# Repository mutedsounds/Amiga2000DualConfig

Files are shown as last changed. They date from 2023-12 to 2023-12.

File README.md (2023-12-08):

# Amiga2000DualConfig
Amiga 2000 Coprocessor Board to support 2 selectable CPUs, 2 selectable kickstart ROMs (+ 2x A/B configuration options) at boot or reset.

The **DualConfig** project was born out of an observation: some programs, games or demos don't work with all 680x0 processor models or all kickstart versions.

This project allows you to run the Amiga 2000 in legacy mode (68000 & Kickstart1.3) or with the legacy CPU and a more recent kickstart (68000 & Kickstart 3.x) or with a TerribleFire-type card (68030 & Kickstart3.x) for instance. It also provides two additional controls, one can be used to control a DF0 selector for instance. 

There is no need to power-off the Amiga to change the configuration. It can be changed anytime while the Amiga is powered-on. It will be taken in account on the next reset. Each of the 4 configuration parameters (CPU, Kickstart, param3, param4) can be selected using a latched SPST Off-On switch, with optional illumination.

The solution consists of two PCBs:

1. A "DualCpuAdapter" card that fits into the coprocessor slot. It is inspired by the [Open Amiga 2000 Copro Adapter](https://github.com/SukkoPera/OpenAmiga2000CoproAdapter) project. It allows:

   a) permanent installation of two CPUs in the Amiga with selection of one of the two installed CPUs via a SPST latched Off-On switch;

   b) selection of one of two Kickstarts via a SPST latch Off-On switch;

   c) optionally two other configuration parameters, each controlled via a latchsed SPST Off-On switch, one can be used to drive a ["DF0 Selector" board with a SPST control interface such as the one developped by Jussi Kilpelainen](https://jussikilpelainen.kapsi.fi/wordpress/?p=256)

   d) a led illumination driver for each parameter, enabling the use of illuminated switches 

2. A "DualKickAdapter" card that fits in the Kickstart DIP40 slot, allowing a permanent installation of two kickstart ROMs in the Amiga. Kickstart selection can be controlled either by the "DualCpuAdapter" card or by a DPDT On-On switch. 

The "DualKickAdapter" can be controlled by the "DualCpuAdapter" board by connecting 2 wires from the KICK1_CSn & KICK2_CSn header pins of the "DualCpuAdapter" board to the middle pins of the 2x3 header "SW DPDT", CSn_A & CSn_B.

The [CIT Relay GH Series](http://citrelay.com/view_switch.php?series=GH) are illuminated SPST latching off-on pushbutton switches with a small enough diameter of 10mm to be installed on the lower area of the bottom chassis of the Amiga 2000.

I made this project initially for personal use. It is operational and free of license. 

|:warning:**IMPORTANT: The KiCad files provided in the github repository have been translated from another commercial PCB design tool. The latest beta version (7.99) is required to open the files. I strongly advise to double check the KiCad PCB design files before sending to production. Please feel free to propose document updates.** |
|-----------------------------------------|

DualCpuAdapter, CPU1 side  | DualCpuAdapter, CPU2 side | DualKickAdapter
:-------------------------:|:-------------------------:|:-------------------------:
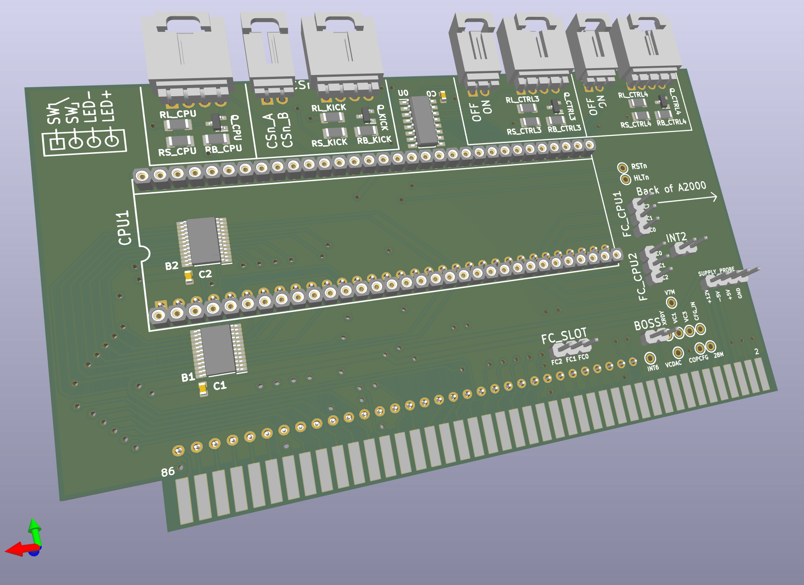
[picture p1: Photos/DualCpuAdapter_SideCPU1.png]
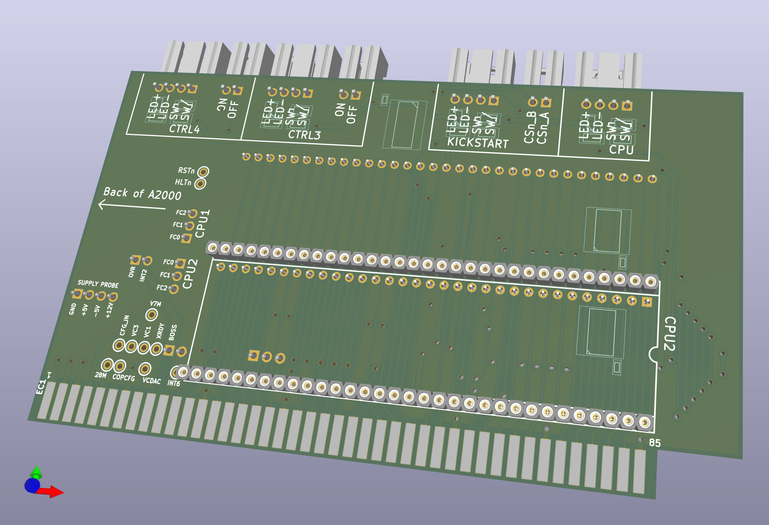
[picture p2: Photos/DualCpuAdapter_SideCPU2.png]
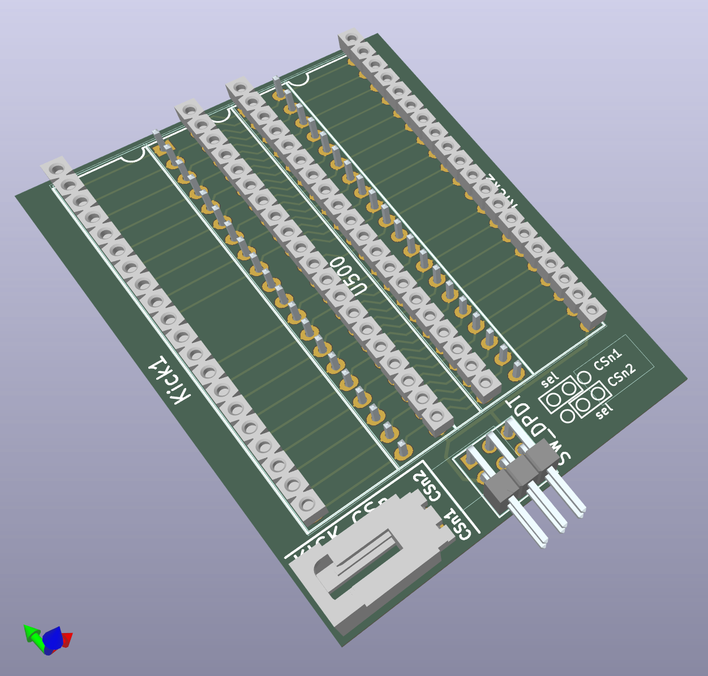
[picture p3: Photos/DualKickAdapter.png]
|  |  |  |

:camera:CIT Relay GH Series Pushbutton Switches to select CPU model (red on the left) and Kickstart version (green on the right)
|-----------------------------------------|

Legacy configuration 68000 (switch off) with Kickstart 1.3 (switch off) | Legacy CPU 68000 (switch off) with Kickstart 3.2.2 (switch on) | TF536 accelerator (switch on) with Kickstart 3.2.2 (switch on)
:-------------------------:|:-------------------------:|:-------------------------:
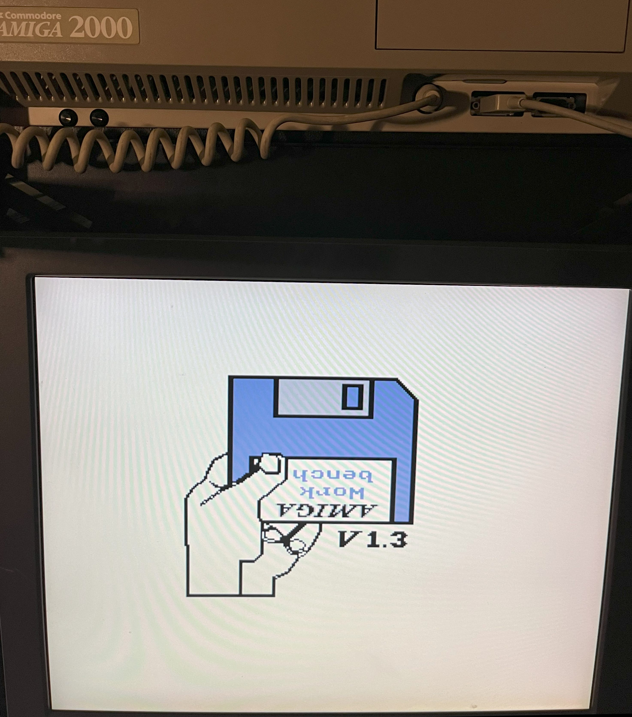
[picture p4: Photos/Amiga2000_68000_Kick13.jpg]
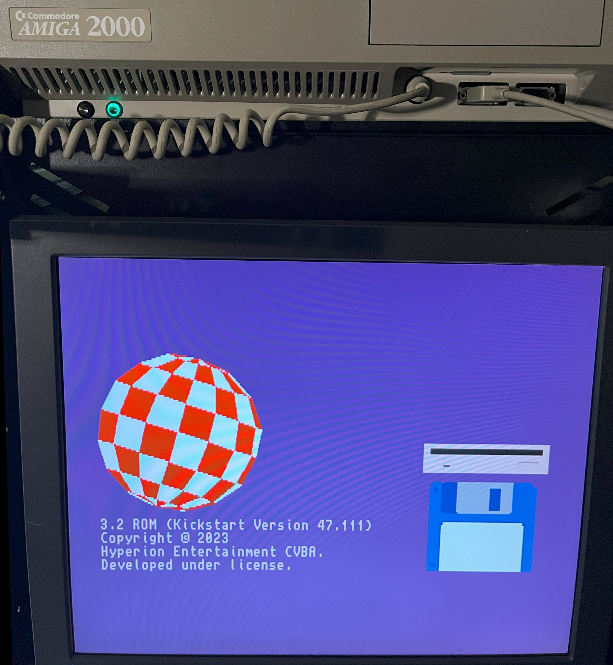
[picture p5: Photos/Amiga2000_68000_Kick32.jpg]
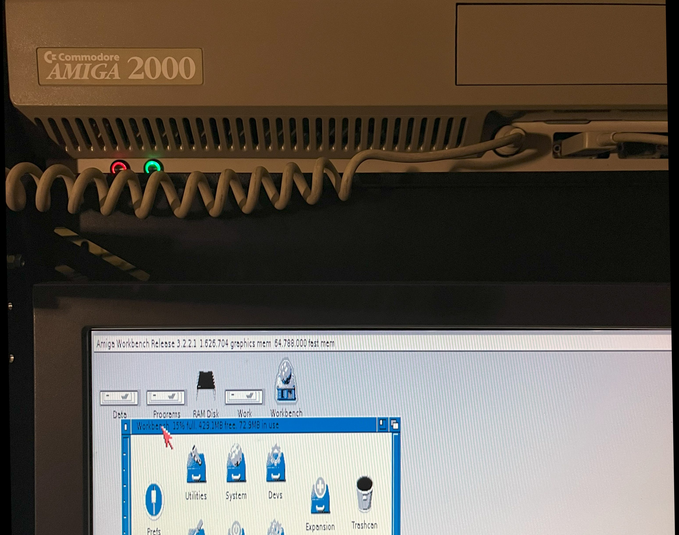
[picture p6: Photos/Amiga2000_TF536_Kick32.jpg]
|  |  |  |

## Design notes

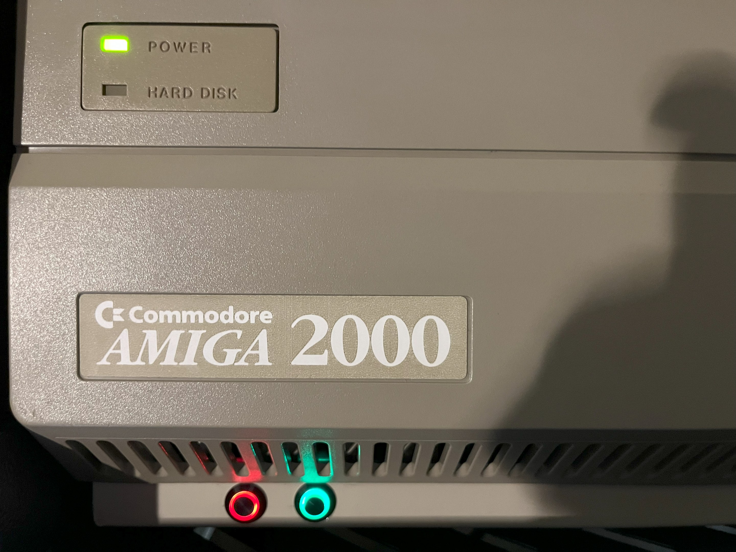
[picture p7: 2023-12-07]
Photos/Amiga2000_CPUred_KICKgreen_pushbuttons.jpg

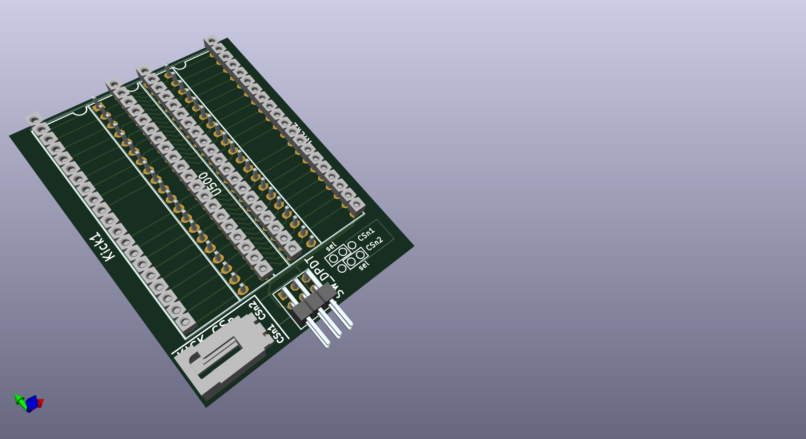
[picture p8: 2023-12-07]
DualKickAdapter/DualKickAdapter.png

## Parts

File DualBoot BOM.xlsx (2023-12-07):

Board | Designator | Digikey Part # | Manufacturer | Manufacturer Part | Description | Q. | Comments
Chassis | SW_CPU | 2449-GHLEBBRN-ND | CIT | GHLEBBRN | SPST Push-Button Off-On Latching D=10mm Illuminated Red | 1 | CPU selector, diameter small enough to be mounted on the front of the main chassis
DualCpu | SW_CPU | WM4902-ND | Molex | 705530003 | 2.54mm 1x4 pos, SL Header, Right Angle | 1 | Connect to CPU illuminated SPST switch (header must mate the cable receptacle)
DualCpu | SW_CPU | 900-2162711044-ND | Molex | 2162711044 | 2.54mm 1x4 pos, SL Female-to-Pigtail Off-the-Shelf (OTS) Cable Assembly, Length 600mm | 1 | Cable assembly to illuminated SPST switch (receptacle must mate the header)
Chassis | SW_KICK | 2449-GHLEBBGN-ND | CIT | GHLEBBGN | SPST Push-Button Off-On Latching D=10mm Illuminated Green | 1 | Kick selector, diameter small enough to be mounted on the front of the main chassis
DualCpu | SW_KICK | WM4902-ND | Molex | 705530003 | 2.54mm 1x4 pos, SL Header, Right Angle | 1 | Connect to KICK illuminated SPST switch (header must mate the cable receptacle)
DualCpu | SW_KICK | 900-2162711044-ND | Molex | 2162711044 | 2.54mm 1x4 pos, SL Female-to-Pigtail Off-the-Shelf (OTS) Cable Assembly, Length 600mm | 1 | Cable assembly to illuminated SPST switch (receptacle must mate the header)
DualCpu | KICK_CSn | WM4900-ND | Molex | 705530001 | 2.54mm 1x2 pos, SL Header, Right Angle | 1 | Connect to DualKick board
DualCpu | KICK_CSn | 900-2162701024-ND | Molex | 2162701024 | 2,54mm 1x2 pos, SL Male-to-SL Male Off-the-Shelf (OTS) Cable Assembly Length 600mm | 1 | Cable assembly to DualKick board
DualCpu | SW_CTRL3, SW_CTRL4 | WM4902-ND | Molex | 705530003 | 2.54mm 1x4 pos, SL Header, Right Angle | 0 | OPTIONAL, Connector to (illuminated) SPST switch
DualCpu | SW_CTRL3, SW_CTRL4 | 900-2162711044-ND | Molex | 2162711044 | 2.54mm 1x4 pos, SL Female-to-Pigtail Off-the-Shelf (OTS) Cable Assembly, Length 600mm | 0 | OPTIONAL, Cable assembly to (illuminated) SPST switch
DualCpu | CTRL3, CTRL4 | WM4900-ND | Molex | 705530001 | 2.54mm 1x2 pos, SL Header, Right Angle | 0 | OPTIONAL, Connector to control cable
DualCpu | SUPPLY | 952-3286-ND | Harwin | M20-9960445 | 2.54mm 1x4 pos, SL Header, Right Angle | 0 | OPTIONAL
DualCpu | BOSS, INT2 | M20-9770242-ND | Harwin | M20-9770242 | 2.54mm 1x2 pos Header, Straight | 0 | OPTIONAL
DualCpu | B1, B2 | 296-26449-5-ND | Texas Instruments | SN74CBTD3861PW | IC BUS SWITCH 10 X 1:1 24TSSOP | 2 | 10-bit FET bus to switch CPU outputs
DualCpu | C0, C1, C2 | 1276-1006-1-ND | Samsung E-M | CL10B104KA8NNNC | CAP CER 0.1UF 25V X7R 0603 | 3 | Decoupling caps
DualCpu | CPU1, CPU2 | 952-1938-ND | Harwin | D01-9973242 | CONN SOCKET SIP 32POS GOLD | 4 | 2x SIP 32-pin per CPU
DualCpu | Q_CPU, Q_CTRL3, Q_CTRL4, Q_KICK | 1727-1135-1-ND | Nexperia USA Inc. | PMBT2222A,235 | TRANS NPN 40V 0.6A TO236AB | 4 | LED driver for each control
DualCpu | RB_CPU, RB_CTRL3, RB_CTRL4, RB_KICK, RS_CPU, RS_CTRL3, RS_CTRL4, RS_KICK | 13-RC1206FR-134K7LCT-ND | YAGEO | RC1206FR-134K7L | RES 4.7K OHM 1% 1/4W 1206 | 8 | SW+LED driver for each control
DualCpu | RL_CPU, RL_CTRL3, RL_CTRL4, RL_KICK | 13-RC1206JR-13120RLCT-ND | YAGEO | RC1206JR-13120RL | RES 120 OHM 5% 1/4W 1206 | 4 | LED driver for each control
DualCpu | U0 | 296-31495-1-ND |  | CD4042BDR | IC QUAD CLOCKED D LATCH 16SOIC | 1 | Sample & Hold Switch Position on deassertion of reset
DualKick | SW_DPDT | WM4900-ND | Molex | 705530001 | 2.54mm 1x2 pos, SL Header, Right Angle | 1 | Connect to DualKick board, to be soldered in the mid 2 pins of the 2x3 footprint
DualKick | SW_DPDT | 10129382-906002BLF-ND | Amphenol | 10129382-906002BLF | CONN HEADER R/A 6POS 2.54MM | 0 | If direct connection to a DPDT switch, only the 2 middle pins are required to connect to the DualKick board
DualKick | U500 | ED7564-20-ND | Mill-Max Mfr Corp. | 800-10-020-10-002000 | CONN HEADER VERT 20POS 2.54MM | 2 | 2x SIP 20-pin male-male to plug the board in the U500 socket
DualKick | Kick1, Kick2 | Z12503-ND | Omron EMC | XR2C-2011-N | CONN SOCKET SIP 20POS GOLD | 4 | 2x SIP 20-pin socket per Kickstart

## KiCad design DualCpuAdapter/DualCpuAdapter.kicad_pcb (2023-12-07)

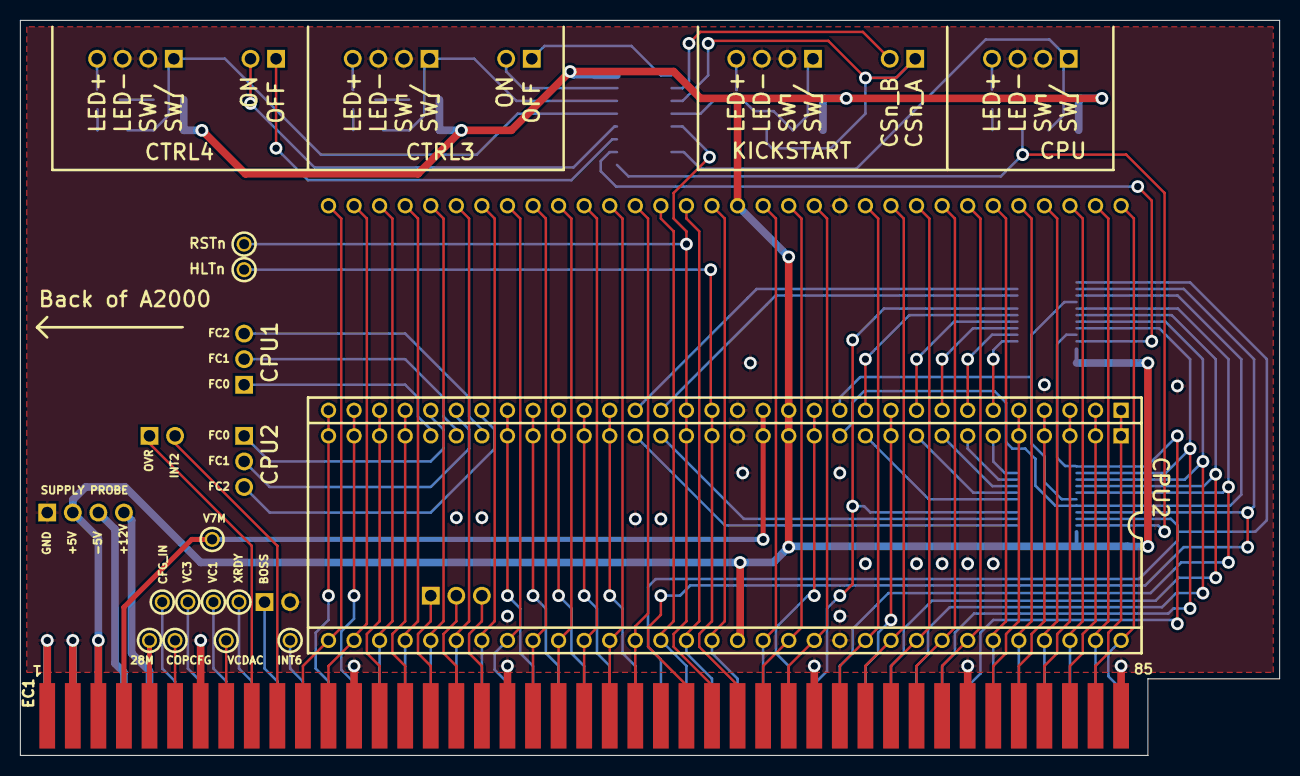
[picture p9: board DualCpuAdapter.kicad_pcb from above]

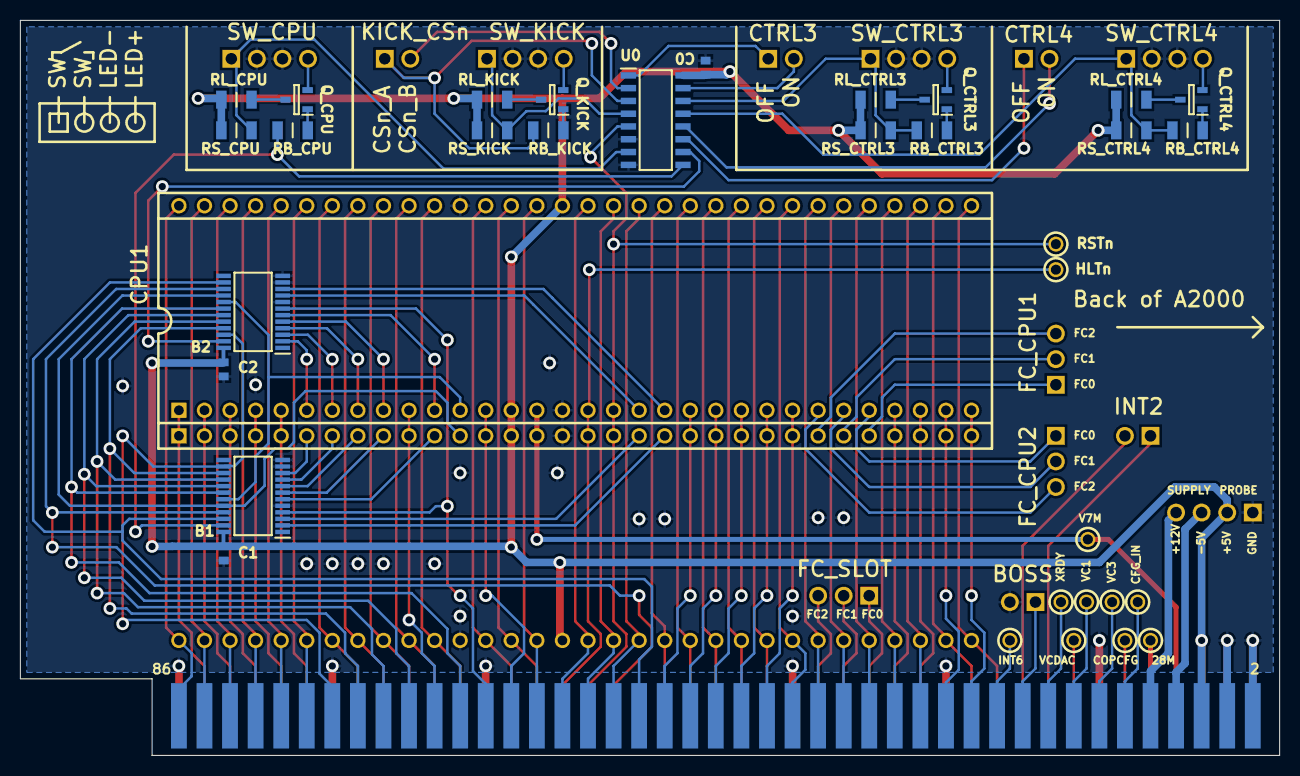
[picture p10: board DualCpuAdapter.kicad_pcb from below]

Board: 2 copper layers, 125.1 x 73.0 mm, 49 parts (47 on the bottom side), 111 nets.

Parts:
28M: Test Point; Test Point Throughhole 60mil
B1, B2: SN74CBTD3861PWR; SOP65P640X120-24N
BOSS: Header 1x2 SSS; Harwin M20-9770246
C0, C1, C2: X7R; SMD 1608 X95N
CFG_IN: Test Point; Test Point Throughhole 60mil
COPCFG: Test Point; Test Point Throughhole 60mil
CPU1, CPU2: MC68000P; DIP64 900mil 2xSIP32
CTRL3, CTRL4: Header 1x2 SSS; Molex 705530001
EC1: Card Edge 86pos; Card Edge 86DS 100mil
FC_CPU1, FC_CPU2: Header 1x3 SSS; Harwin M20-9770346
FC_SLOT: Header 1x3 SSS; Harwin M20-9770346
HLTn: Test Point; Test Point Throughhole 60mil
INT2: Header 1x2 SSS; Harwin M20-9770246
INT6: Test Point; Test Point Throughhole 60mil
KICK_CSn: Header 1x2 SSS; Molex 705530001
Q_CPU: PMBT2222A_235; SOT95P230X110-3N
Q_CTRL3, Q_CTRL4: PMBT2222A_235; SOT95P230X110-3N
Q_KICK: PMBT2222A_235; SOT95P230X110-3N
RB_CPU: %; SMD C3216 X 60N
RB_CTRL3, RB_CTRL4: %; SMD C3216 X 60N
RB_KICK: %; SMD C3216 X 60N
RL_CPU: %; SMD C3216 X 60N
RL_CTRL3, RL_CTRL4: %; SMD C3216 X 60N
RL_KICK: %; SMD C3216 X 60N
RSTn: Test Point; Test Point Throughhole 60mil
RS_CPU: %; SMD C3216 X 60N
RS_CTRL3, RS_CTRL4: %; SMD C3216 X 60N
RS_KICK: %; SMD C3216 X 60N
SUPPLY: Header 1x4 SSS; Harwin M20-9770446
SW_CPU: Header 1x4 SSS; Molex 705530003
SW_CTRL3, SW_CTRL4: Header 1x4 SSS; Molex 705530003
SW_KICK: Header 1x4 SSS; Molex 705530003
U0: CD4042BDR; SOIC127P600X175-16N
V7M: Test Point; Test Point Throughhole 60mil
VC1, VC3: Test Point; Test Point Throughhole 60mil
VCDAC: Test Point; Test Point Throughhole 60mil
XRDY: Test Point; Test Point Throughhole 60mil

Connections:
+5V: B1.24 (VCC), B2.24 (VCC), C0.1, C1.1, C2.1, CPU1.14 (VCC), CPU1.49 (VCC), CPU2.14 (VCC), CPU2.49 (VCC), EC1.5, EC1.6, RL_CPU.1, RL_CTRL3.1, RL_CTRL4.1, RL_KICK.1, RS_CPU.2, RS_CTRL3.2, RS_CTRL4.2, RS_KICK.2, SUPPLY.2, U0.16 (VDD)
+12V: EC1.10, SUPPLY.4
-5V: EC1.8, SUPPLY.3
/A1: CPU1.29 (A1), CPU2.29 (A1), EC1.29
/A2: CPU1.30 (A2), CPU2.30 (A2), EC1.27
/A3: CPU1.31 (A3), CPU2.31 (A3), EC1.26
/A4: CPU1.32 (A4), CPU2.32 (A4), EC1.24
/A5: CPU1.33 (A5), CPU2.33 (A5), EC1.21
/A6: CPU1.34 (A6), CPU2.34 (A6), EC1.23
/A7: CPU1.35 (A7), CPU2.35 (A7), EC1.28
/A8: CPU1.36 (A8), CPU2.36 (A8), EC1.30
/A9: CPU1.37 (A9), CPU2.37 (A9), EC1.32
/A10: CPU1.38 (A10), CPU2.38 (A10), EC1.34
/A11: CPU1.39 (A11), CPU2.39 (A11), EC1.36
/A12: CPU1.40 (A12), CPU2.40 (A12), EC1.38
/A13: CPU1.41 (A13), CPU2.41 (A13), EC1.39
/A14: CPU1.42 (A14), CPU2.42 (A14), EC1.41
/A15: CPU1.43 (A15), CPU2.43 (A15), EC1.43
/A16: CPU1.44 (A16), CPU2.44 (A16), EC1.45
/A17: CPU1.45 (A17), CPU2.45 (A17), EC1.47
/A18: CPU1.46 (A18), CPU2.46 (A18), EC1.52
/A19: CPU1.47 (A19), CPU2.47 (A19), EC1.54
/A20: CPU1.48 (A20), CPU2.48 (A20), EC1.56
/A21: CPU1.50 (A21), CPU2.50 (A21), EC1.58
/A22: CPU1.51 (A22), CPU2.51 (A22), EC1.57
/A23: CPU1.52 (A23), CPU2.52 (A23), EC1.59
/ASn_CPU1: B1.10 (A9), CPU1.6 (~AS)
/ASn_CPU2: B2.2 (A1), CPU2.6 (~AS)
/ASn_SLOT: B1.14 (B9), B2.22 (B1), EC1.74
/BERRn: CPU1.22 (~BERR), CPU2.22 (~BERR), EC1.46
/BGACKn_CPU1: B1.20 (B3), B2.16 (B7), CPU1.12 (~BGACK)
/BGACKn_CPU2: B1.19 (B4), B2.17 (B6), CPU2.12 (~BGACK)
/BGACKn_SLOT: B1.4 (A3), B2.7 (A6), EC1.62
/BGn_CPU1: B1.6 (A5), CPU1.11 (~BG)
/BGn_CPU2: B2.6 (A5), CPU2.11 (~BG)
/BGn_SLOT: B1.18 (B5), B2.18 (B5), EC1.64
/BRn: CPU1.13 (~BR), CPU2.13 (~BR), EC1.60
/CPU1_SELn: B1.23 (~OE), U0.9 (~Q2)
/CPU2_SELn: B2.23 (~OE), U0.10 (Q2)
/CTRL3_OFF: CTRL3.1, U0.1 (Q4)
/CTRL3_ON: CTRL3.2, U0.15 (~Q4)
/CTRL3_SW: RB_CTRL3.1, RS_CTRL3.1, SW_CTRL3.1, U0.14 (D4)
/CTRL4_OFF: CTRL4.1, U0.11 (Q3)
/CTRL4_ON: CTRL4.2, U0.12 (~Q3)
/CTRL4_SW: RB_CTRL4.1, RS_CTRL4.1, SW_CTRL4.1, U0.13 (D3)
/D0: CPU1.5 (D0), CPU2.5 (D0), EC1.75
/D1: CPU1.4 (D1), CPU2.4 (D1), EC1.77
/D2: CPU1.3 (D2), CPU2.3 (D2), EC1.79
/D3: CPU1.2 (D3), CPU2.2 (D3), EC1.81
/D4: CPU1.1 (D4), CPU2.1 (D4), EC1.83
/D5: CPU1.64 (D5), CPU2.64 (D5), EC1.86
/D6: CPU1.63 (D6), CPU2.63 (D6), EC1.84
/D7: CPU1.62 (D7), CPU2.62 (D7), EC1.82
/D8: CPU1.61 (D8), CPU2.61 (D8), EC1.80
/D9: CPU1.60 (D9), CPU2.60 (D9), EC1.78
/D10: CPU1.59 (D10), CPU2.59 (D10), EC1.76
/D11: CPU1.58 (D11), CPU2.58 (D11), EC1.71
/D12: CPU1.57 (D12), CPU2.57 (D12), EC1.69
/D13: CPU1.56 (D13), CPU2.56 (D13), EC1.67
/D14: CPU1.55 (D14), CPU2.55 (D14), EC1.65
/D15: CPU1.54 (D15), CPU2.54 (D15), EC1.63
/DTACKn: CPU1.10 (~DTACK), CPU2.10 (~DTACK), EC1.66
/E_CPU1: B1.2 (A1), CPU1.20 (E)
/E_CPU2: B2.10 (A9), CPU2.20 (E)
/E_SLOT: B1.22 (B1), B2.14 (B9), EC1.50
/FC0_CPU1: CPU1.28 (FC0), FC_CPU1.1
/FC0_CPU2: CPU2.28 (FC0), FC_CPU2.1
/FC1_CPU1: CPU1.27 (FC1), FC_CPU1.2
/FC1_CPU2: CPU2.27 (FC1), FC_CPU2.2
/FC2_CPU1: CPU1.26 (FC2), FC_CPU1.3
/FC2_CPU2: CPU2.26 (FC2), FC_CPU2.3
/HLTn: CPU1.17 (~HALT), CPU2.17 (~HALT), EC1.55
/INT2: EC1.19, INT2.2
/INT6: EC1.22, INT6.1
/IPL0n: CPU1.25 (~IPL0), CPU2.25 (~IPL0), EC1.40
/IPL1n: CPU1.24 (~IPL1), CPU2.24 (~IPL1), EC1.42
/IPL2n: CPU1.23 (~IPL2), CPU2.23 (~IPL2), EC1.44
/LDSn_CPU1: B1.8 (A7), CPU1.8 (~LDS)
/LDSn_CPU2: B2.4 (A3), CPU2.8 (~LDS)
/LDSn_SLOT: B1.16 (B7), B2.20 (B3), EC1.70
/OVR: EC1.17, INT2.1
/RSTn: CPU1.18 (~RST), CPU2.18 (~RST), EC1.53, U0.5 (CLOCK)
/RWn_CPU1: B1.7 (A6), CPU1.9 (R/~W)
/RWn_CPU2: B2.5 (A4), CPU2.9 (R/~W)
/RWn_SLOT: B1.17 (B6), B2.19 (B4), EC1.68
/UDSn_CPU1: B1.9 (A8), CPU1.7 (~UDS)
/UDSn_CPU2: B2.3 (A2), CPU2.7 (~UDS)
/UDSn_SLOT: B1.15 (B8), B2.21 (B2), EC1.72
/V7M: CPU1.15 (CLK), CPU2.15 (CLK), EC1.7
/VC1: EC1.16, VC1.1
/VC3: EC1.14, VC3.1
/VMAn_CPU1: B1.3 (A2), CPU1.19 (~VMA)
/VMAn_CPU2: B2.9 (A8), CPU2.19 (~VMA)
/VMAn_SLOT: B1.21 (B2), B2.15 (B8), EC1.51
/VPAn: CPU1.21 (~VPA), CPU2.21 (~VPA), EC1.48
CPU_LED: Q_CPU.2, SW_CPU.4
CPU_SW: RS_CPU.1, SW_CPU.1
GND: B1.5 (A4), B1.11 (A10), B1.12 (GND), B2.8 (A7), B2.11 (A10), B2.12 (GND), BOSS.2, C0.2, C1.2, C2.2, CPU1.16 (GND), CPU1.53 (GND), CPU2.16 (GND), CPU2.53 (GND), EC1.1, EC1.2, EC1.3, EC1.4, EC1.13, EC1.25, EC1.37, EC1.49, EC1.61, EC1.73, EC1.85, SUPPLY.1, SW_CPU.2, SW_CPU.3, SW_CTRL3.2, SW_CTRL3.3, SW_CTRL4.2, SW_CTRL4.3, SW_KICK.2, SW_KICK.3, U0.6 (POLARITY), U0.8 (VSS)
KICK1_CSN: KICK_CSn.1, RB_KICK.1
KICK_SW: RS_KICK.1, SW_KICK.1
unnamed: Q_CTRL3.1 (B), RB_CTRL3.2
unnamed: Q_CTRL3.3 (C), RL_CTRL3.2
unnamed: Q_CTRL3.2 (E), SW_CTRL3.4
unnamed: Q_CTRL4.1 (B), RB_CTRL4.2
unnamed: Q_CTRL4.3 (C), RL_CTRL4.2
unnamed: Q_CTRL4.2 (E), SW_CTRL4.4
NetQ_CPU_1: Q_CPU.1, RB_CPU.2
NetQ_CPU_3: Q_CPU.3, RL_CPU.2
NetQ_KICK_1: Q_KICK.1, RB_KICK.2
NetQ_KICK_2: Q_KICK.2, SW_KICK.4
NetQ_KICK_3: Q_KICK.3, RL_KICK.2

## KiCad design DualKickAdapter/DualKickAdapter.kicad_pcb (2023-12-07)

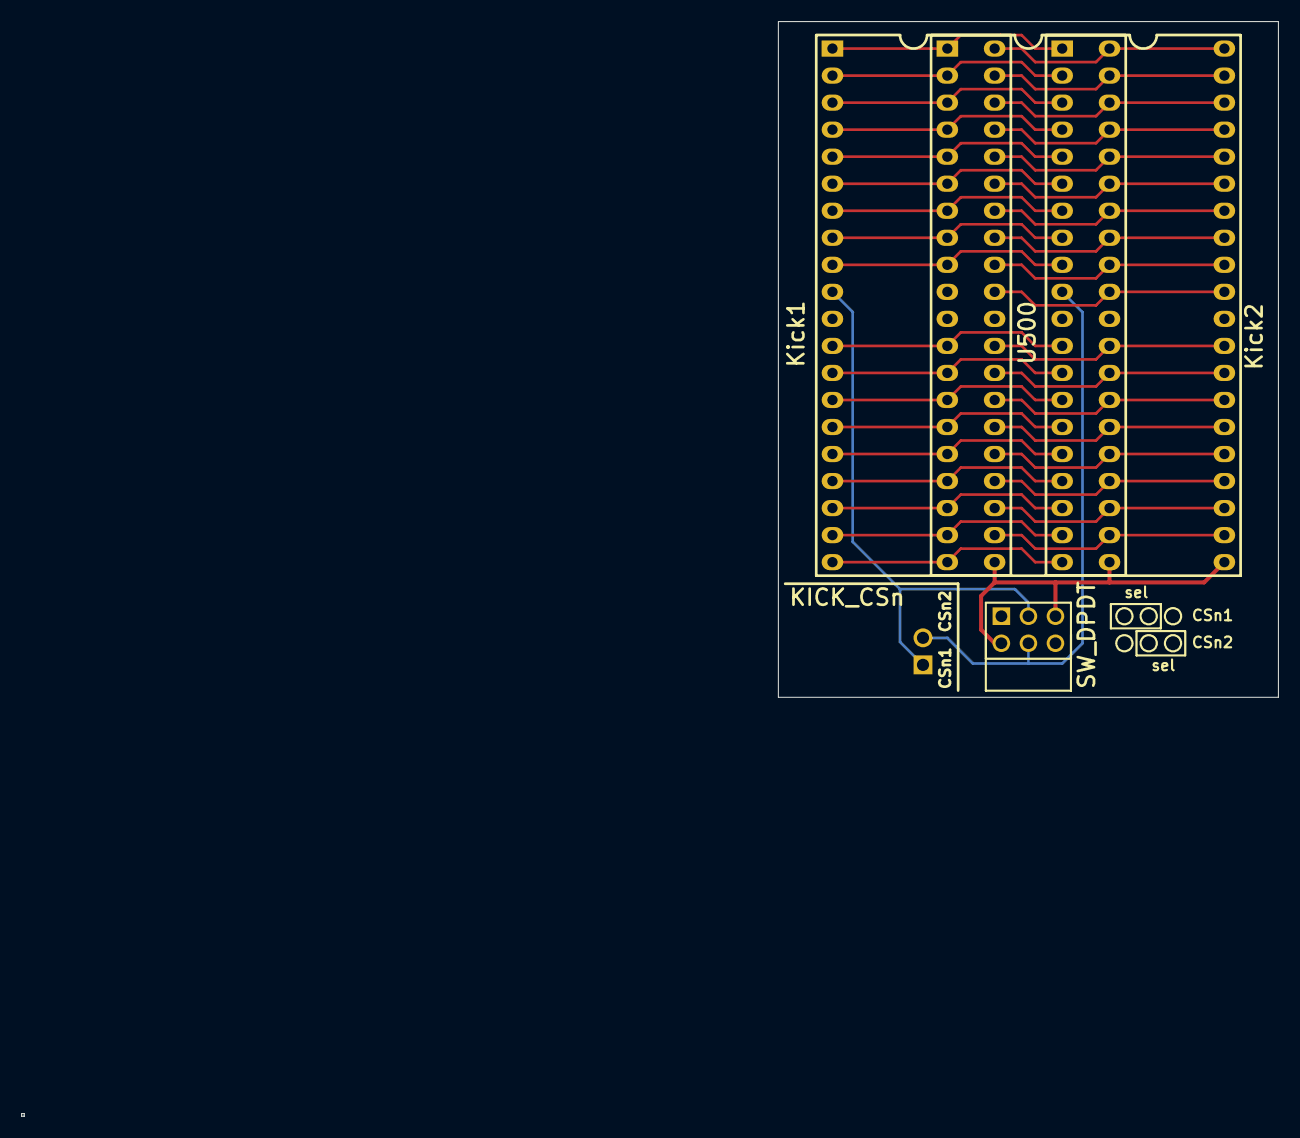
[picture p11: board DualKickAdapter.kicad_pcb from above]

Board: 2 copper layers, 47.0 x 63.5 mm, 5 parts (0 on the bottom side), 40 nets.

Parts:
KICK_CSn: Header 1x2 DSS; Molex 705530001
Kick1, Kick2: DIP40 2x20 600mil; DIP40 600mil 2xSIP20 oval
SW_DPDT: Header 2x3 DSS; Amphenol 10129382-906002BLF alt
U500: DIP40 2x20 600mil; DIP40 600mil 2xSIP20 spacer oval

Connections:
A0: Kick1.9, Kick2.9, U500.9
A1: Kick1.8, Kick2.8, U500.8
A2: Kick1.7, Kick2.7, U500.7
A3: Kick1.6, Kick2.6, U500.6
A4: Kick1.5, Kick2.5, U500.5
A5: Kick1.4, Kick2.4, U500.4
A6: Kick1.3, Kick2.3, U500.3
A7: Kick1.2, Kick2.2, U500.2
A8: Kick1.40, Kick2.40, U500.40
A9: Kick1.39, Kick2.39, U500.39
A10: Kick1.38, Kick2.38, U500.38
A11: Kick1.37, Kick2.37, U500.37
A12: Kick1.36, Kick2.36, U500.36
A13: Kick1.35, Kick2.35, U500.35
A14: Kick1.34, Kick2.34, U500.34
A15: Kick1.33, Kick2.33, U500.33
A16: Kick1.32, Kick2.32, U500.32
A17: Kick1.31, Kick2.31, U500.31
CSN_A: KICK_CSn.1, SW_DPDT.3
CSN_B: KICK_CSn.2, SW_DPDT.4
D0: Kick1.13, Kick2.13, U500.13
D1: Kick1.15, Kick2.15, U500.15
D2: Kick1.17, Kick2.17, U500.17
D3: Kick1.19, Kick2.19, U500.19
D4: Kick1.22, Kick2.22, U500.22
D5: Kick1.24, Kick2.24, U500.24
D6: Kick1.26, Kick2.26, U500.26
D7: Kick1.28, Kick2.28, U500.28
D8: Kick1.14, Kick2.14, U500.14
D9: Kick1.16, Kick2.16, U500.16
D10: Kick1.18, Kick2.18, U500.18
D11: Kick1.20, Kick2.20, U500.20
D12: Kick1.23, Kick2.23, U500.23
D13: Kick1.25, Kick2.25, U500.25
D14: Kick1.27, Kick2.27, U500.27
D15: Kick1.29, Kick2.29, U500.29
GND: Kick1.11, Kick1.30, Kick2.11, Kick2.30, SW_DPDT.1, SW_DPDT.6, U500.11, U500.30
NC: Kick1.1, Kick2.1, U500.1
OEn: Kick1.12, Kick2.12, U500.12
VCC: Kick1.21, Kick2.21, SW_DPDT.2, SW_DPDT.5, U500.21

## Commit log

2023-12-06 Kicad files for CpuSelector Board and KickstartSelector board added
    [CpuSelector7.kicad_pcb, CpuSelector7.kicad_sch, KickstartSelector7.kicad_pcb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]
2023-12-07 BOM added
    TO BE VERIFIED: does the proposed Molex connector 705530001 fit in the mid 2-pin of the SW_DPDT footprint of the DualKick board?
    [DualBoot BOM.xlsx]
2023-12-07 Restructuring: each board has its own folder; Added: snapshots of boards and amiga case
    [CpuSelector7.kicad_pcb, CpuSelector7.kicad_sch, DualCpuAdapter.kicad_pcb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]
2023-12-08 Update README.md: added required Kicad version 7.99 (8 beta)
2023-12-08 Update README.md: PCB board snapshots added
2023-12-08 [Photos] PCB snapshots reframed
